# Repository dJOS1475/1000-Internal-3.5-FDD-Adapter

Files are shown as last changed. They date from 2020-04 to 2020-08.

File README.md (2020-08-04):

# 1000-Internal-3.5-FDD-Adapter
Tandy 1000 Internal 3.5" FDD Adapter

This Tandy 1000 Internal Floppy Drive Adapter allows you to add an extra Drive or replace your dead Floppy Drive in Tandy 1000's that send power over the Floppy cable. All you need is an Amiga / Atari ST style Floppy Power cable (as shown) and a compatible Standard 3.5" Floppy Drive. Most drives made up-to-the mid-'90s should work well, but after that compatibility is very much hit and miss as Shugart support was dropped by many OEM's to reduce drive costs.

Tandy 1000's that have power supplied via the Floppy Cable include the HX, SL/2, TX, TL, TL/2, TL/3.

For this adapter to work, the rear of the replacement floppy drive should have a similar connector arrangement as the pictured drives - the power connector must at least 12mm away from the Floppy ribbon connector and the floppy ribbon connector notch must be on the bottom of the drive (look for the notch in the PCB).

I made these because many folks want to add a 2nd drive or replace a dead Floppy Drive in their Tandy 1000's but due to the non-standard power-over-cable-design were unable to find a compatible replacement drive.

My Store can be found here: https://www.tindie.com/stores/CyberneticSys/

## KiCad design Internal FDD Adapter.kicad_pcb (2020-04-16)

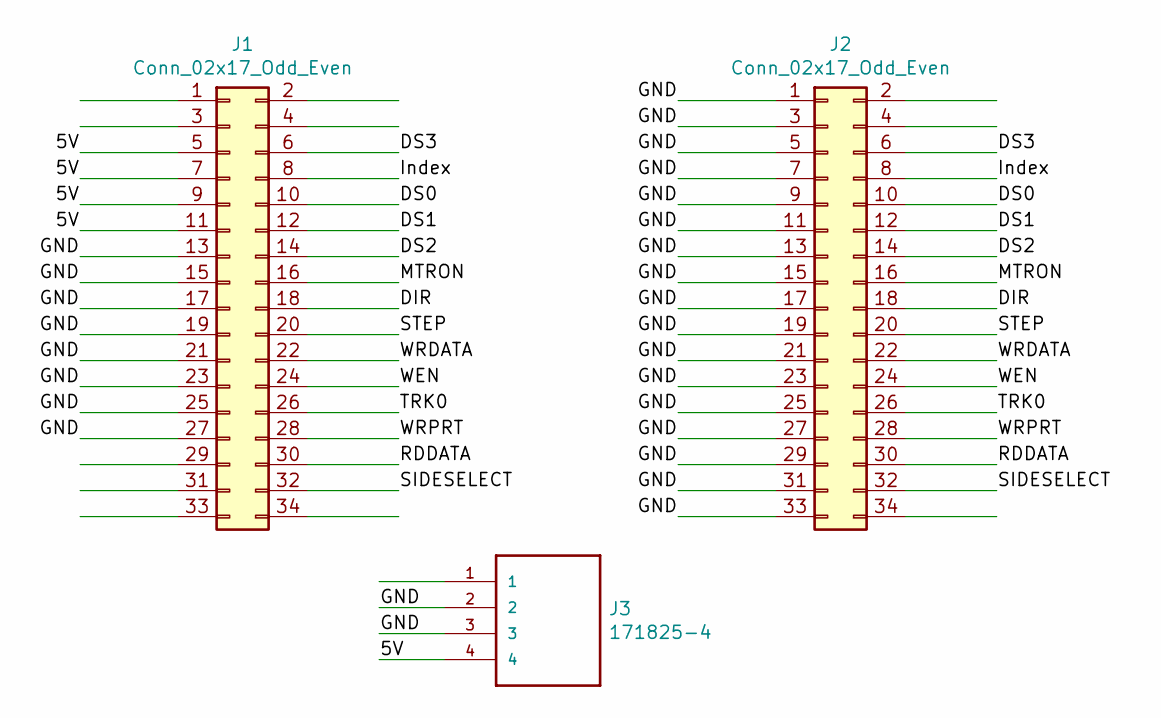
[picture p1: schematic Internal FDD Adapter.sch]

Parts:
J1: Conn_02x17_Odd_Even; IDC34M
J2: Conn_02x17_Odd_Even; IDC34F
J3: 171825-4; Molex_KK-254_AE-6410-04A_1x04_P2.54mm_Vertical

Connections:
/5V: J1.5, J1.7, J1.9, J1.11, J3.4
/DIR: J1.18, J2.18
/DS0: J1.10, J2.10
/DS1: J1.12, J2.12
/DS2: J1.14, J2.14
/DS3: J1.6, J2.6
/GND: J1.13, J1.15, J1.17, J1.19, J1.21, J1.23, J1.25, J1.27, J2.1, J2.3, J2.5, J2.7, J2.9, J2.11, J2.13, J2.15, J2.17, J2.19, J2.21, J2.23, J2.25, J2.27, J2.29, J2.31, J2.33, J3.2, J3.3
/Index: J1.8, J2.8
/MTRON: J1.16, J2.16
/RDDATA: J1.30, J2.30
/SIDESELECT: J1.32, J2.32
/STEP: J1.20, J2.20
/TRK0: J1.26, J2.26
/WEN: J1.24, J2.24
/WRDATA: J1.22, J2.22
/WRPRT: J1.28, J2.28

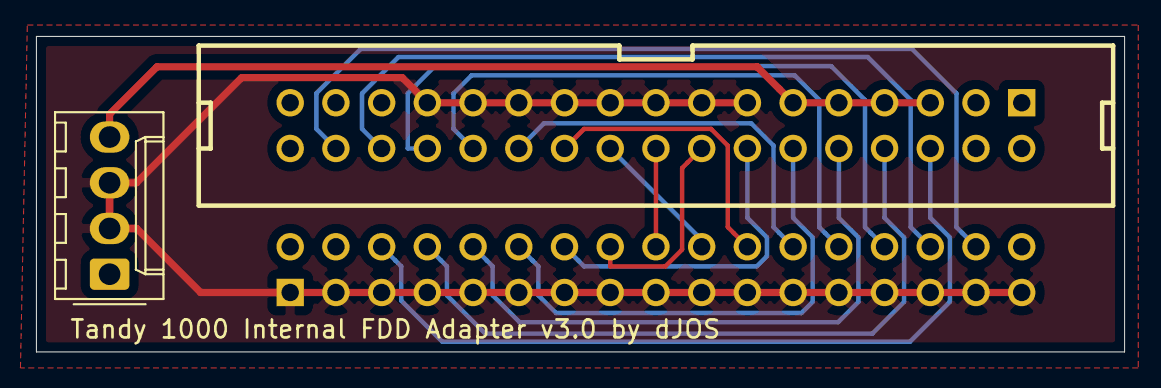
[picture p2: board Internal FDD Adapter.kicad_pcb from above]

Board: 2 copper layers, 60.5 x 17.5 mm, 3 parts (1 on the bottom side), 16 nets.
